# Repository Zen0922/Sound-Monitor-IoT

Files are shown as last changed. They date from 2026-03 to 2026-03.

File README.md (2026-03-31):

# 🎧 Sound Monitor IoT

ESP32センサーとRaspberry Piを使用したIoT音量監視システム
IoT sound monitoring system using ESP32 sensors and Raspberry Pi

---

## 🧠 概要 / Overview

複数の音量センサーからデータを収集し、Raspberry Piをゲートウェイとしてデータベースに蓄積、Web UIおよびディスプレイに可視化するシステムです。
This system collects sound data from distributed sensors, stores it via a Raspberry Pi gateway, and visualizes it on a web dashboard and display.

---

## 🏗️ システム構成 / Architecture

```text
[ESP32 Sound Sensor]
        ↓ (BLE)
[Raspberry Pi Gateway]
        ├─ Data Collection (Python)
        ├─ MariaDB
        └─ Web Server (PHP)
        ↓
[Web Dashboard / Kiosk Display]
```

---

## 📁 ディレクトリ構成 / Project Structure

```text
Sound-Monitor-IoT/
├── docs/                            # ドキュメント / Documentation
│   └── （設計資料・画像など）
│
├── firmware/                        # センサーデバイス側
│   └── esp32s3_sound_sensor/        # ESP32用ファームウェア
│       └── （BLE送信・音量測定）
│
├── gateway/                         # Raspberry Pi側（中核）
│   └── （Pythonスクリプト・systemd等）
│       ├── collector / データ収集
│       ├── detector / デバイス検出
│       ├── brightness / 明度制御
│       └── kiosk / 表示制御
│
├── hardware/                        # ハード設計
│   └── enclosure/
│       └── sensor/                  # センサーケース（3Dデータ等）
│
├── web/                             # Webアプリケーション
│   └── （PHP UI・設定画面）
│
├── .gitignore
├── LICENSE
└── README.md
```

---

## 🧩 各フォルダの役割 / Directory Roles

### firmware/

ESP32センサーデバイスのファームウェア
Firmware for ESP32-based sound sensor devices

* 音量取得（マイク）
* BLEでデータ送信

---

### gateway/

Raspberry Pi側の中核処理
Core processing on Raspberry Pi

主な役割：

* BLEスキャン・データ収集
* センサーデバイス検出
* データベース保存
* 明度制御
* kiosk表示制御

---

### web/

可視化および操作UI
Web-based dashboard and control interface

主な役割：

* 音量表示
* センサー管理
* 閾値設定

---

### hardware/

ハードウェア設計データ
Hardware design assets

主な内容：

* センサーケース（3Dプリント用）
* 設置用パーツ

---

### docs/

ドキュメント・画像
Documentation and images

主な用途：

* 構成図
* スクリーンショット
* 設計資料

---

## ⚙️ システム構成（機能単位） / Functional Components

| 機能 | 内容 |
| --- | --- |
| センサー | ESP32 + マイクで音量測定 |
| 通信 | BLE広告パケット |
| ゲートウェイ | Raspberry Pi |
| DB | MariaDB |
| 表示 | PHP + Chromium kiosk |
| 制御 | systemd |

---

## 🚀 セットアップ（概要） / Setup (Overview)

※詳細は各ディレクトリ内を参照
See each directory for detailed setup instructions.

---

## 🛠 技術スタック / Tech Stack

* Raspberry Pi OS
* Python 3
* PHP
* MariaDB
* Bluetooth Low Energy (BLE)
* systemd

---

## 📌 今後の予定 / Roadmap

* MQTT対応
  MQTT support

* クラウド連携
  Cloud integration

* UI改善（円形最適化）
  UI improvements (circular optimization)

* 自動アップデート
  Auto update system

---

## 📄 ライセンス / License

MIT License

---

## 👤 Author

Zen
GitHub: https://github.com/Zen0922

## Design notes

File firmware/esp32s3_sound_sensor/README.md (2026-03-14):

# ESP32S3 Sound Sensor Firmware
ESP32S3 sound sensor firmware for Sound Monitor IoT.

## Hardware

- Seeed Studio XIAO ESP32S3
- ICS-43434 MEMS microphone

ICS-43434 は I2S 接続のデジタル MEMS マイクです。  
そのため、I2S インターフェースを持つ ESP32-S3 を使用しています。  
ESP32-C3 など、I2S をサポートしていないマイコンでは動作しません。

The ICS-43434 is a digital MEMS microphone that uses the I2S interface.  
Therefore this project uses an ESP32-S3 which supports I2S.  
Microcontrollers without I2S support, such as ESP32-C3, cannot be used.

## Files

- `main.py`  
  メインのファイルです。
  Main firmware entry point
- `soundsensor_db.py`
  RMS計算や相対dB変換などの音声処理ロジックを実装しています
  Sound processing logic such as RMS calculation and relative dB conversion

## Overview

このファームウェアは、I2Sマイクから音声サンプルを読み取り、相対的な音量レベルを計算し、BLEで送信します。
This firmware reads audio samples from an I2S microphone, calculates a relative sound level,
and transmits the value via BLE.

---

## Transmitted Values / 送信値

BLEペリフェラルは以下の値を提供します。
The BLE peripheral provides the following values.

### `level`

相対音量レベルです。値は10倍スケールです。
Relative sound level value (x10 scale).

Example:

- `153` = `15.3 dB`
- `87` = `8.7 dB`

これが主な監視値です。
This is the main monitoring value.

---

### `baseline`

現在のベースラインRMS値です。値は10倍スケールです。
これは物理的なdB値ではありません。  
相対音量を計算するための内部基準値です。

Current baseline RMS value (x10 scale).
This is not a physical dB value.
It is an internal reference value used to calculate relative sound level.

---

### `aux1`

予約値です。現在は `0` 固定です。
Reserved value. Currently fixed to `0`.

---

### `aux2`

予約値です。現在は `0` 固定です。
Reserved value. Currently fixed to `0`.

---

## Calculation Method / 計算方法

### 1. RMS calculation / RMS計算

センサーは 32bit stereo の I2S サンプルを読み取り、通常は片チャネル (`pick="L"`) を使用します。  
値は 8bit 右シフトして実質24bit信号として扱います。
The sensor reads 32-bit stereo I2S samples and uses one channel (`pick="L"` by default).
The value is converted to an effective 24-bit signal by shifting right by 8 bits.

RMS計算の前にDC成分の除去を行います。
A DC removal filter is applied before RMS calculation.

RMSはサンプル値の二乗平均平方根として計算します。
The RMS is calculated from the squared sample values.

---

### 2. Initial baseline / 初期ベースライン

起動時に短いキャリブレーションを行い、複数のRMSサンプルを収集します。
収集した値のうち下位20%を取り出し、その中央値を初期 `noise_rms` として採用します。
この方式により、起動時の一時的な物音の影響を受けにくくしています。

At startup, the firmware performs a short calibration.
During this phase, multiple RMS samples are collected.
The lower 20% of the collected values are extracted,
and the median of that lower range is used as the initial `noise_rms`.
This design makes the baseline more resistant to temporary noise during startup.

---

### 3. Relative dB calculation / 相対dB計算

主な音量レベルは次の式で計算されます。
The main sound level is calculated as:
`relative_dB = 20 * log10(rms / noise_rms)`

Important:

重要:

- これは絶対音圧の dB SPL ではありません
- 学習された基準値に対する相対値です
したがって送信値は、「静かな基準状態に対して、現在どれだけ大きいか」を示す値として解釈してください。

- This is **not absolute SPL dB**
- This is a **relative value against the learned baseline**
Therefore, the transmitted value should be interpreted as
“how much louder the current sound is compared with the quiet baseline.”

---

### 4. Smoothing / 平滑化

相対dB値には指数移動平均 (EMA) による平滑化をかけています。
さらに、短時間の突発的なスパイクを抑えるため、3点メディアンフィルタを適用しています。
また、不自然な急変を抑えるため、変化量の上限も設けています。

The relative dB value is smoothed with exponential moving average (EMA).
In addition, a median-of-3 filter is applied to suppress short spikes.
A maximum step limit is also used to avoid unrealistic sudden jumps.

---

### 5. 3-second window aggregation / 3秒窓での集約

センサーは生の値をそのまま毎回送信するのではなく、3秒間の値を集約して送信します。
送信する `level` は、3秒窓内の平滑化済み値の 90 パーセンタイルです。
この方式を採用した理由は次の通りです。

- 意味のある物音に反応しやすい
- 1サンプルだけのスパイクに引きずられにくい
- 瞬間最大値より安定している

The sensor does not transmit every raw sample.
Instead, values are collected for 3 seconds and aggregated.
The transmitted `level` is the 90th percentile of the filtered values in the 3-second window.
This design was chosen because:

- it reacts to meaningful sound events
- it is less sensitive to one-sample spikes
- it is more stable than sending an instantaneous peak

---

## Quiet Baseline Learning / 静寂ベースライン学習

起動後も、静寂時のベースライン学習を継続します。
以下の条件を満たしたときのみ更新します。

- 十分なサンプル数が集まっている
- 更新クールダウン時間を過ぎている
- 候補値が現在のベースラインより十分低い

更新は即時置き換えではなく、徐々に反映されます。
これにより、長期的な環境変化には追従しつつ、不安定な動作を避けています。

After startup, the firmware continues learning the quiet baseline.
It periodically stores RMS samples and updates the baseline only when:

- enough samples have been collected
- the cooldown period has passed
- the candidate value is sufficiently lower than the current baseline

The update is applied gradually instead of replacing the baseline immediately.
This helps the sensor adapt to long-term environmental changes while avoiding unstable behavior.

---

## Important Notes / 注意事項

- 送信される `level` は **相対指標** であり、校正済みの音圧レベルではありません。
- マイク個体差や取り付け条件により生値は変動します。
- この値は、傾向監視、相対比較、しきい値判定に向いています。

- The transmitted `level` is a **relative index**, not a calibrated SPL measurement.
- Different microphones and mounting conditions may produce different raw levels.
- The value is suitable for monitoring trends, relative loudness, and threshold-based alerting.

---

## Current Parameters / 現在の主なパラメータ

- サンプリング周波数: `32000 Hz`
- 集約窓長: `3000 ms`
- サンプル間隔: `100 ms`
- 窓出力: `90パーセンタイル`
- 初期校正時間: 約 `2秒`
- ピークホールド: `1000 ms`
- 時間重み付け: `FAST`

- Sample rate: `32000 Hz`
- Window length: `3000 ms`
- Sample interval: `100 ms`
- Window output: `90th percentile`
- Initial calibration time: about `2 seconds`
- Peak hold: `1000 ms`
- Time weighting: `FAST`

## Image
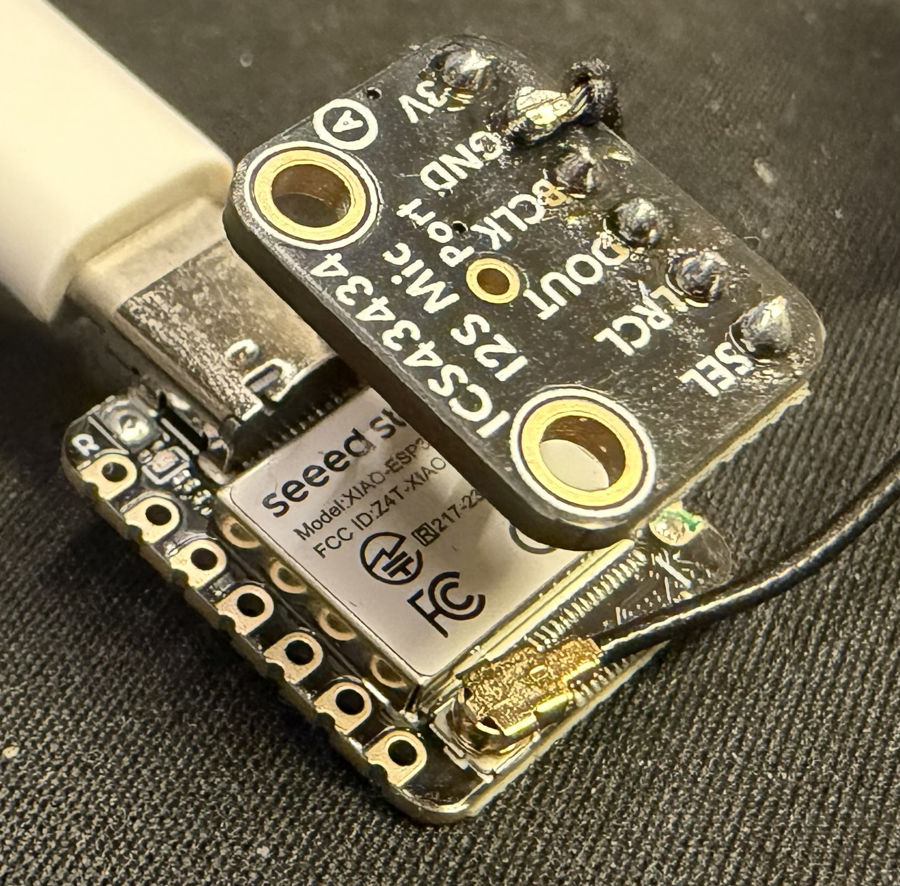
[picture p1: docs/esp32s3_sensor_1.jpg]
Sensor

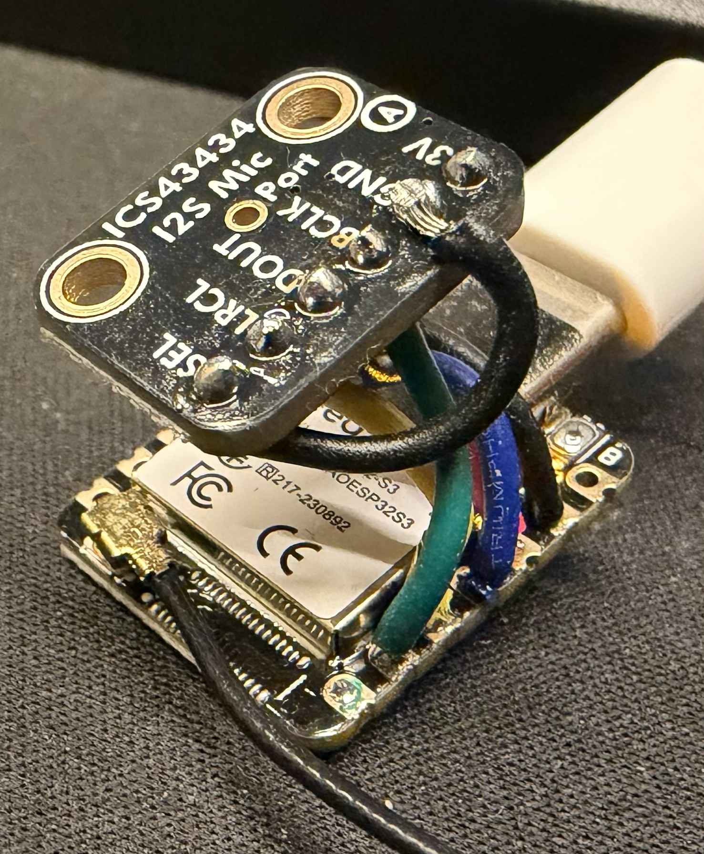
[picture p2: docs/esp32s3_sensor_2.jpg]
Sensor


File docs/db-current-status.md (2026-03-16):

\# DB Current Status

\## Database

\- name: sound\_monitor

\## Notes

\- This directory stores the current live database schema exported from Raspberry Pi.

\- `sql/current/current\_schema.sql` is the snapshot of the live schema.

\- These files are for review and migration planning.

\## Main tables

\- sensor\_device

\- sensor\_value

\- detected\_sensor\_device

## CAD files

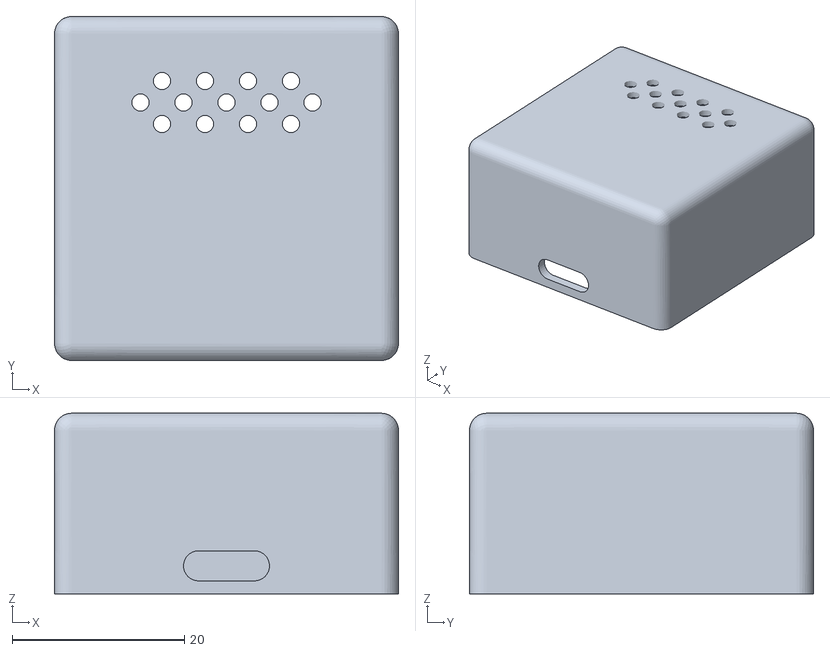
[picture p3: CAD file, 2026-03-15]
hardware/enclosure/sensor/sensor_frame.stl
40.0 x 40.0 x 21.0

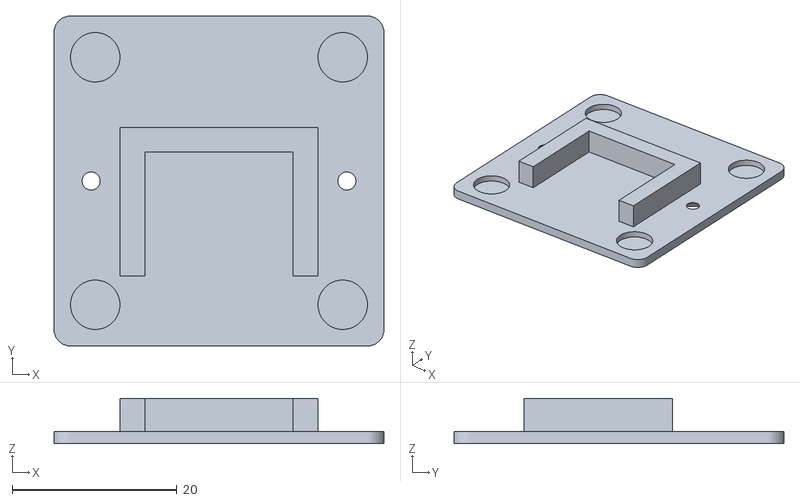
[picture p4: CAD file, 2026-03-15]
hardware/enclosure/sensor/sensor_base.stl
40.0 x 40.0 x 5.50

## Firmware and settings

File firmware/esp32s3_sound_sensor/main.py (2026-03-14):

# main_fixedgatt.py
"""
Sound Monitor IoT
ESP32 Sound Sensor Firmware

Hardware
- XIAO ESP32S3
- ICS-43434 MEMS Microphone

Function
- Measure sound level
- Calculate RMS
- Convert to relative dB
- Send data via BLE
"""
import time
import struct

try:
    import bluetooth
except ImportError:
    import ubluetooth as bluetooth

from soundsensor_db import SoundSensor

NAME_PREFIX = "RP-SoundSensor-"
WINDOW_MS = 3000
SAMPLE_INTERVAL_MS = 100

ENABLE_SECURITY = False
REQUIRE_ENCRYPTED_TO_NOTIFY = False

_SOUND_SERVICE_UUID = bluetooth.UUID("c0de0001-3b3a-4f2c-9a3a-1b2c3d4e5001")
_SOUND_LEVEL_UUID   = bluetooth.UUID("c0de0002-3b3a-4f2c-9a3a-1b2c3d4e5001")
_BASELINE_UUID      = bluetooth.UUID("c0de0003-3b3a-4f2c-9a3a-1b2c3d4e5001")
_AUX1_UUID          = bluetooth.UUID("c0de0004-3b3a-4f2c-9a3a-1b2c3d4e5001")
_AUX2_UUID          = bluetooth.UUID("c0de0005-3b3a-4f2c-9a3a-1b2c3d4e5001")

_FLAG_READ = bluetooth.FLAG_READ
_FLAG_NOTIFY = bluetooth.FLAG_NOTIFY

_IRQ_CENTRAL_CONNECT = 1
_IRQ_CENTRAL_DISCONNECT = 2
PERCENTILE = 0.90
MAX_STEP_DB_X10 = 200


def _make_adv_field(field_type: int, value: bytes) -> bytes:
    return bytes((len(value) + 1, field_type)) + value


def _adv_payload_split(name: str):
    adv = _make_adv_field(0x01, b"\x06")
    resp = _make_adv_field(0x09, name.encode())
    return adv, resp


class StatusLED:
    def __init__(self):
        self._mode = "none"
        self._pin = None
        self._np = None

        try:
            import neopixel
            from machine import Pin
            for p in ("NEOPIXEL", "RGB", "RGBLED"):
                try:
                    pin = Pin(p, Pin.OUT)
                    self._np = neopixel.NeoPixel(pin, 1)
                    self._mode = "neopixel"
                    self.off()
                    return
                except Exception:
                    pass
        except Exception:
            pass

        try:
            from machine import Pin
            try:
                self._pin = Pin("LED", Pin.OUT)
                self._mode = "pin"
                self.off()
                return
            except Exception:
                pass
        except Exception:
            pass

    def on(self):
        if self._mode == "pin":
            self._pin.value(1)
        elif self._mode == "neopixel":
            self._np[0] = (20, 20, 0)
            self._np.write()

    def off(self):
        if self._mode == "pin":
            self._pin.value(0)
        elif self._mode == "neopixel":
            self._np[0] = (0, 0, 0)
            self._np.write()

    def toggle(self, state: bool):
        self.on() if state else self.off()


class SoundBlePeripheral:
    def __init__(self):
        self._ble = bluetooth.BLE()
        self._ble.active(True)
        self._ble.irq(self._irq)

        handles = self._ble.gatts_register_services((
            (_SOUND_SERVICE_UUID, (
                (_SOUND_LEVEL_UUID, _FLAG_READ | _FLAG_NOTIFY),
                (_BASELINE_UUID, _FLAG_READ | _FLAG_NOTIFY),
                (_AUX1_UUID, _FLAG_READ | _FLAG_NOTIFY),
                (_AUX2_UUID, _FLAG_READ | _FLAG_NOTIFY),
            )),
        ))
        ((self._level_handle, self._baseline_handle, self._aux1_handle, self._aux2_handle),) = handles
        self._connections = set()

        mac = self._ble.config("mac")
        if isinstance(mac, tuple):
            mac = mac[1]
        self._addr = ":".join("{:02X}".format(b) for b in mac)
        self._name = NAME_PREFIX + self._addr.replace(":", "")[-4:]

        self._adv_data, self._resp_data = _adv_payload_split(self._name)
        self._advertise()
        print("GATT fixed handles =", handles)

    def _advertise(self, interval_ms=250):
        self._ble.gap_advertise(
            interval_ms * 1000,
            adv_data=self._adv_data,
            resp_data=self._resp_data,
        )
        print("Advertising:", self._name, "| BT Addr:", self._addr)

    def _irq(self, event, data):
        if event == _IRQ_CENTRAL_CONNECT:
            conn_handle, _, _ = data
            self._connections.add(conn_handle)
            print("Connected:", conn_handle)
        elif event == _IRQ_CENTRAL_DISCONNECT:
            conn_handle, _, _ = data
            self._connections.discard(conn_handle)
            print("Disconnected:", conn_handle)
            self._advertise()

    def _notify_u16(self, handle, value_u16: int):
        v = max(0, min(65535, int(value_u16)))
        payload = struct.pack("<H", v)
        self._ble.gatts_write(handle, payload)
        for ch in list(self._connections):
            try:
                self._ble.gatts_notify(ch, handle, payload)
            except Exception:
                pass

    def notify_all(self, level_u16: int, baseline_u16: int, aux1_u16: int = 0, aux2_u16: int = 0):
        self._notify_u16(self._level_handle, level_u16)
        self._notify_u16(self._baseline_handle, baseline_u16)
        self._notify_u16(self._aux1_handle, aux1_u16)
        self._notify_u16(self._aux2_handle, aux2_u16)


def calibrate_with_blink(sensor, led, seconds=2.0, interval_ms=50, blink_ms=150):
    end = time.ticks_add(time.ticks_ms(), int(seconds * 1000))
    vals = []
    led_state = False
    next_blink = time.ticks_ms()

    while time.ticks_diff(end, time.ticks_ms()) > 0:
        vals.append(sensor._read_rms_24())
        now_ms = time.ticks_ms()
        if time.ticks_diff(now_ms, next_blink) >= 0:
            led_state = not led_state
            led.toggle(led_state)
            next_blink = time.ticks_add(now_ms, blink_ms)
        time.sleep_ms(interval_ms)

    led.off()
    return sensor.set_initial_noise_from_values(vals)


def median3(a, b, c):
    return a + b + c - min(a, b, c) - max(a, b, c)


led = StatusLED()
periph = SoundBlePeripheral()

sensor = SoundSensor(
    bclk_pin=7,
    lrclk_pin=8,
    data_pin=9,
    pick="L",
    time_weight="FAST",
    dc_alpha=0.995,
    peak_hold_ms=1000,
)

print("Calibrating noise... keep silent (LED blinking)")
nf = calibrate_with_blink(sensor, led, seconds=2.0, interval_ms=50, blink_ms=150)
print("Initial noise_rms =", nf)

window_start = time.ticks_ms()
window_values = []
prev_rel10 = None
prev1 = None
prev2 = None

while True:
    rms = sensor._read_rms_24()
    updated = sensor.learn_quiet_baseline(rms)
    if updated:
        print("Baseline updated:", sensor.noise_rms)

    rel10 = sensor.rms_to_dbrel_x10(rms)

    if prev_rel10 is not None:
        delta = rel10 - prev_rel10
        if delta > MAX_STEP_DB_X10:
            rel10 = prev_rel10 + MAX_STEP_DB_X10
        elif delta < -MAX_STEP_DB_X10:
            rel10 = max(0, prev_rel10 - MAX_STEP_DB_X10)

    prev_rel10 = rel10
    filtered = rel10 if (prev1 is None or prev2 is None) else median3(prev2, prev1, rel10)
    prev2 = prev1
    prev1 = rel10
    window_values.append(filtered)

    now_ms = time.ticks_ms()
    if time.ticks_diff(now_ms, window_start) >= WINDOW_MS:
        arr = sorted(window_values) if window_values else [0]
        idx = int(len(arr) * PERCENTILE)
        if idx >= len(arr):
            idx = len(arr) - 1
        level = arr[idx]
        baseline_x10 = int(sensor.noise_rms * 10) if sensor.noise_rms is not None else 0
        aux1 = 0
        aux2 = 0
        print("TX level={:.1f} dB, baseline={:.1f}, aux1={}, aux2={}".format(
            level / 10.0, baseline_x10 / 10.0, aux1, aux2
        ))
        periph.notify_all(level, baseline_x10, aux1, aux2)
        window_values = []
        window_start = now_ms

    time.sleep_ms(SAMPLE_INTERVAL_MS)

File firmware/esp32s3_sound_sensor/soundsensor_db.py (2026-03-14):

from machine import Pin, I2S
import math
import time

LEARN_SAMPLE_INTERVAL_MS = 2000
LEARN_WINDOW_COUNT = 900
LEARN_MIN_COUNT = 120
LEARN_PERCENTILE = 0.10
LEARN_APPLY_RATIO = 0.20
LEARN_REQUIRE_RATIO = 0.98
LEARN_UPDATE_COOLDOWN_MS = 5 * 60 * 1000

class SoundSensor:
    def __init__(
        self,
        bclk_pin,
        lrclk_pin,
        data_pin,
        i2s_id=0,
        sample_rate=32000,
        buffer_frames=1024,
        pick="L",
        time_weight="FAST",
        dc_alpha=0.995,
        peak_hold_ms=1000,
    ):
        self.pick = pick
        self.dc_alpha = dc_alpha
        self._dc = 0.0
        self.noise_rms = None
        self.ema = 0.08 if time_weight == "SLOW" else 0.6
        self._rel_ema = 0.0
        self.peak_hold_ms = peak_hold_ms
        self._peak = 0.0
        self._peak_until = 0
        self._buf = bytearray(buffer_frames * 8)
        self._mv = memoryview(self._buf)

        self.i2s = I2S(
            i2s_id,
            sck=Pin(bclk_pin),
            ws=Pin(lrclk_pin),
            sd=Pin(data_pin),
            mode=I2S.RX,
            bits=32,
            format=I2S.STEREO,
            rate=sample_rate,
            ibuf=len(self._buf) * 2,
        )

        self._learn_values = []
        self._last_learn_sample_ms = time.ticks_ms()
        self._last_learn_update_ms = time.ticks_ms()

        time.sleep_ms(120)
        for _ in range(3):
            try:
                self.i2s.readinto(self._mv)
            except Exception:
                pass
            time.sleep_ms(10)

    @staticmethod
    def _signed32(x):
        x &= 0xFFFFFFFF
        if x & 0x80000000:
            x -= 0x100000000
        return x

    def _read_rms_24(self) -> float:
        n = self.i2s.readinto(self._mv)
        if not n:
            return 0.0
        n = (n // 8) * 8
        if n == 0:
            return 0.0

        offset = 0 if self.pick == "L" else 4
        mv = self._mv
        acc = 0.0
        count = 0
        dc = self._dc
        a = self.dc_alpha

        for i in range(offset, n, 8):
            u = int.from_bytes(mv[i:i+4], "little", False)
            x = self._signed32(u)
            s = x >> 8
            xf = float(s)
            dc = a * dc + (1.0 - a) * xf
            xf = xf - dc
            acc += xf * xf
            count += 1

        self._dc = dc
        if count == 0:
            return 0.0

        rms = math.sqrt(acc / count)
        return max(1.0, rms)

    def set_initial_noise_from_values(self, vals):
        vals = [v for v in vals if v > 0.0]
        vals.sort()
        if not vals:
            self.noise_rms = 1.0
            return self.noise_rms
        cut = max(1, int(len(vals) * 0.2))
        low = vals[:cut]
        self.noise_rms = max(1.0, low[len(low) // 2])
        return self.noise_rms

    def rms_to_dbrel_x10(self, rms: float) -> int:
        if self.noise_rms is None:
            return 0
        rel = 0.0 if rms <= 1e-9 else 20.0 * math.log10(rms / self.noise_rms)
        if rel < 0.0:
            rel = 0.0
        e = self.ema
        self._rel_ema = (1.0 - e) * self._rel_ema + e * rel
        if self.peak_hold_ms and self.peak_hold_ms > 0:
            now = time.ticks_ms()
            if self._rel_ema >= self._peak or time.ticks_diff(self._peak_until, now) <= 0:
                self._peak = self._rel_ema
                self._peak_until = time.ticks_add(now, self.peak_hold_ms)
        return int(self._rel_ema * 10)

    def learn_quiet_baseline(self, rms: float) -> bool:
        if self.noise_rms is None or rms <= 0.0:
            return False
        now = time.ticks_ms()
        if time.ticks_diff(now, self._last_learn_sample_ms) < LEARN_SAMPLE_INTERVAL_MS:
            return False
        self._last_learn_sample_ms = now
        self._learn_values.append(rms)
        if len(self._learn_values) > LEARN_WINDOW_COUNT:
            self._learn_values.pop(0)
        if len(self._learn_values) < LEARN_MIN_COUNT:
            return False
        if time.ticks_diff(now, self._last_learn_update_ms) < LEARN_UPDATE_COOLDOWN_MS:
            return False
        arr = sorted(self._learn_values)
        idx = int(len(arr) * LEARN_PERCENTILE)
        if idx >= len(arr):
            idx = len(arr) - 1
        candidate = max(1.0, arr[idx])
        if candidate < self.noise_rms * LEARN_REQUIRE_RATIO:
            self.noise_rms = max(1.0, (self.noise_rms * (1.0 - LEARN_APPLY_RATIO)) + (candidate * LEARN_APPLY_RATIO))
            self._last_learn_update_ms = now
            return True
        return False

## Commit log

2026-03-14 esp32s3 Script Update
2026-03-14 Add README for ESP32 Sound Sensor firmware
2026-03-14 add sensor image
2026-03-14 Revise README for ESP32S3 Sound Sensor Firmware
    Updated README to reflect changes in project details and functionality.
2026-03-14 gitignore設定 一部確認完了分コミット
2026-03-14 cleanup_sensor_value.pyチェック完了
2026-03-15 センサーケースSTL格納
    [sensor_base.stl, sensor_frame.stl]
2026-03-16 Current database
2026-03-16 current database 2
2026-03-31 serviceとscript
2026-03-31 WAVESHARE-24321用ケース
